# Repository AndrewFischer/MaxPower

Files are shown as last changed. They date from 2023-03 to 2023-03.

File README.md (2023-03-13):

# MaxPower
MaxPower is a dual output buck/boot converter based on the LTC3130. Input power is from an on-board 18650 cell or an external DC source.
Maximum output current is 600mA.<br> 
As shown outputs are 5V and 3.3V. Other voltage pairs are possible. <br>
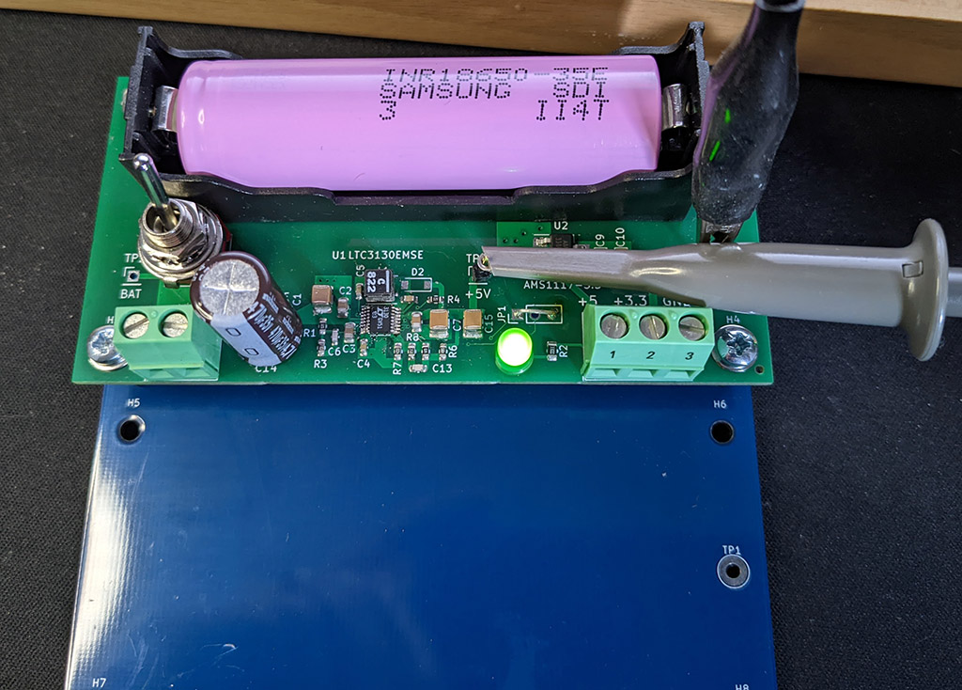
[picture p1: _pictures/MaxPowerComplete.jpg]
Assembled MaxPower


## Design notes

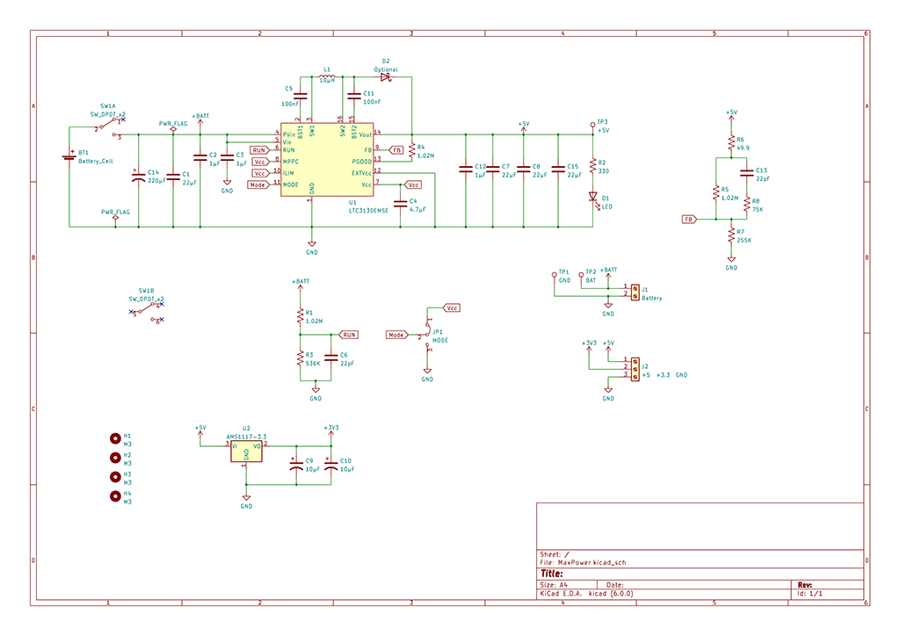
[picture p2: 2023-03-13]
_pictures/MPSchematic.png

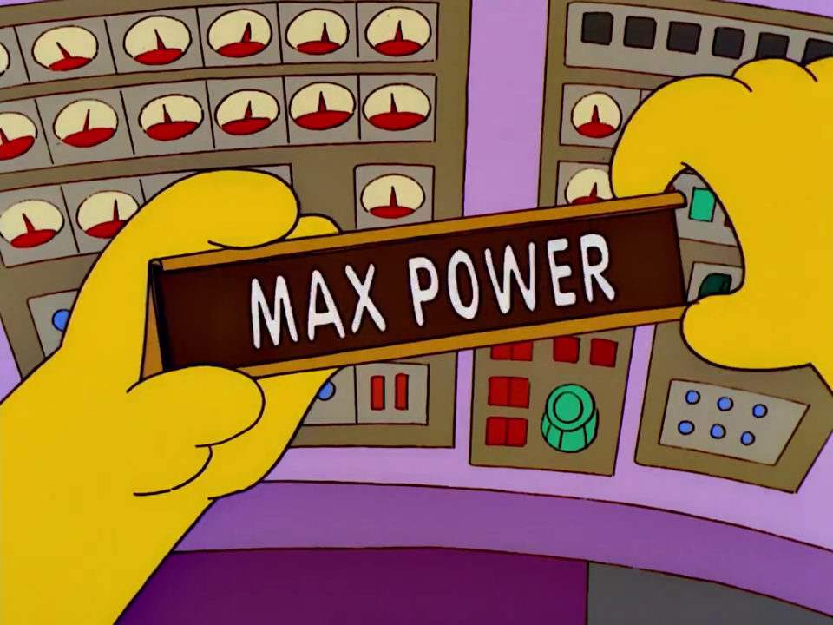
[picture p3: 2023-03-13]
Homer's_new_name.png

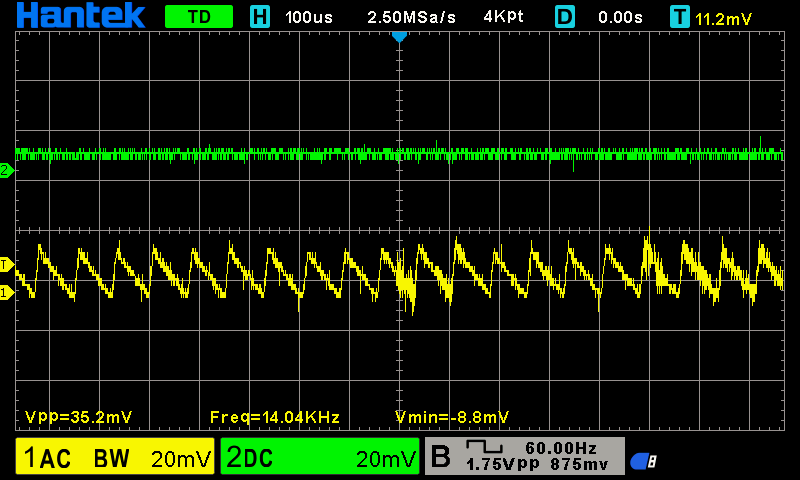
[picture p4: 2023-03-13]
_pictures/NoLoad.png

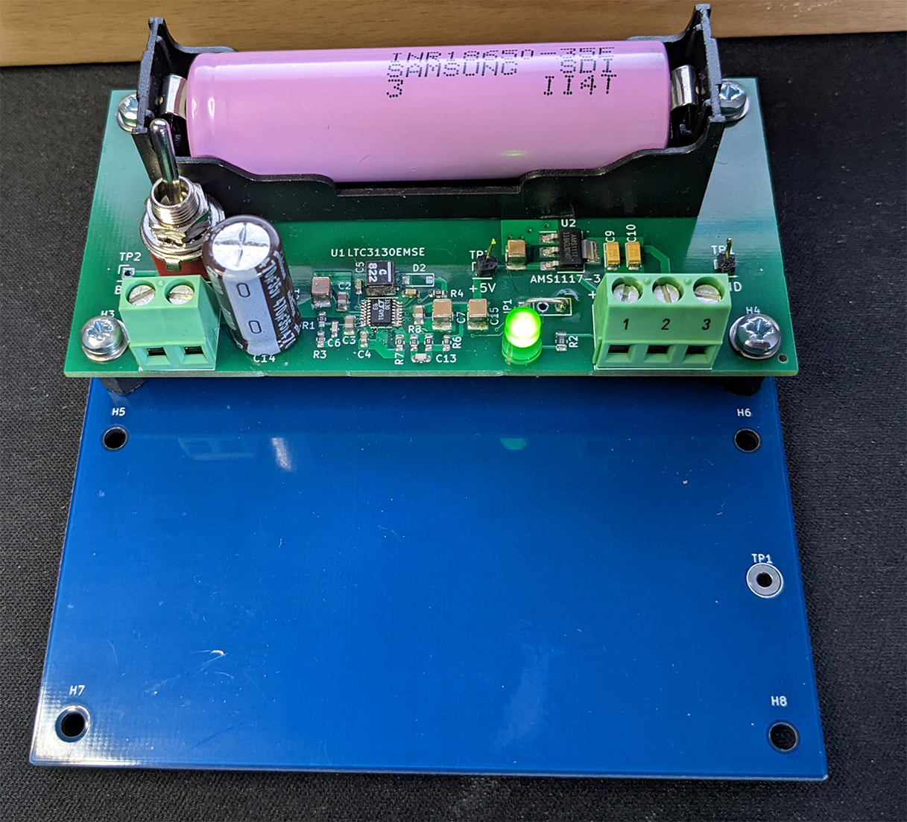
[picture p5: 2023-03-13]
_pictures/Power2.jpg

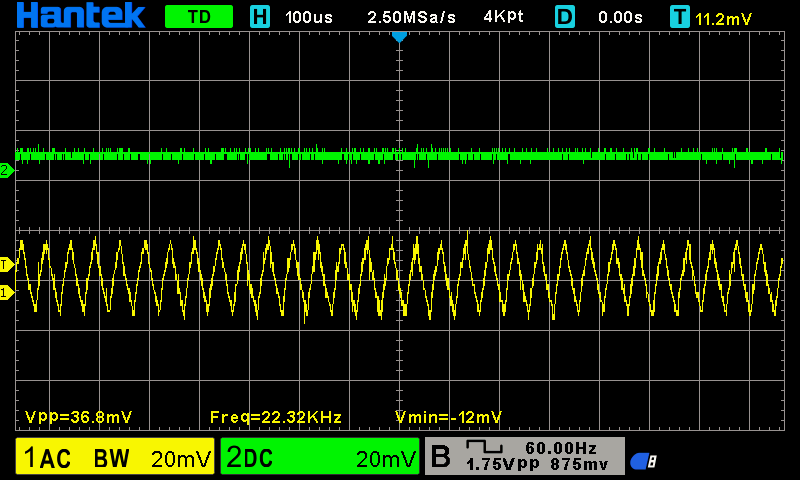
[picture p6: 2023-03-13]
_pictures/LightLoad.png

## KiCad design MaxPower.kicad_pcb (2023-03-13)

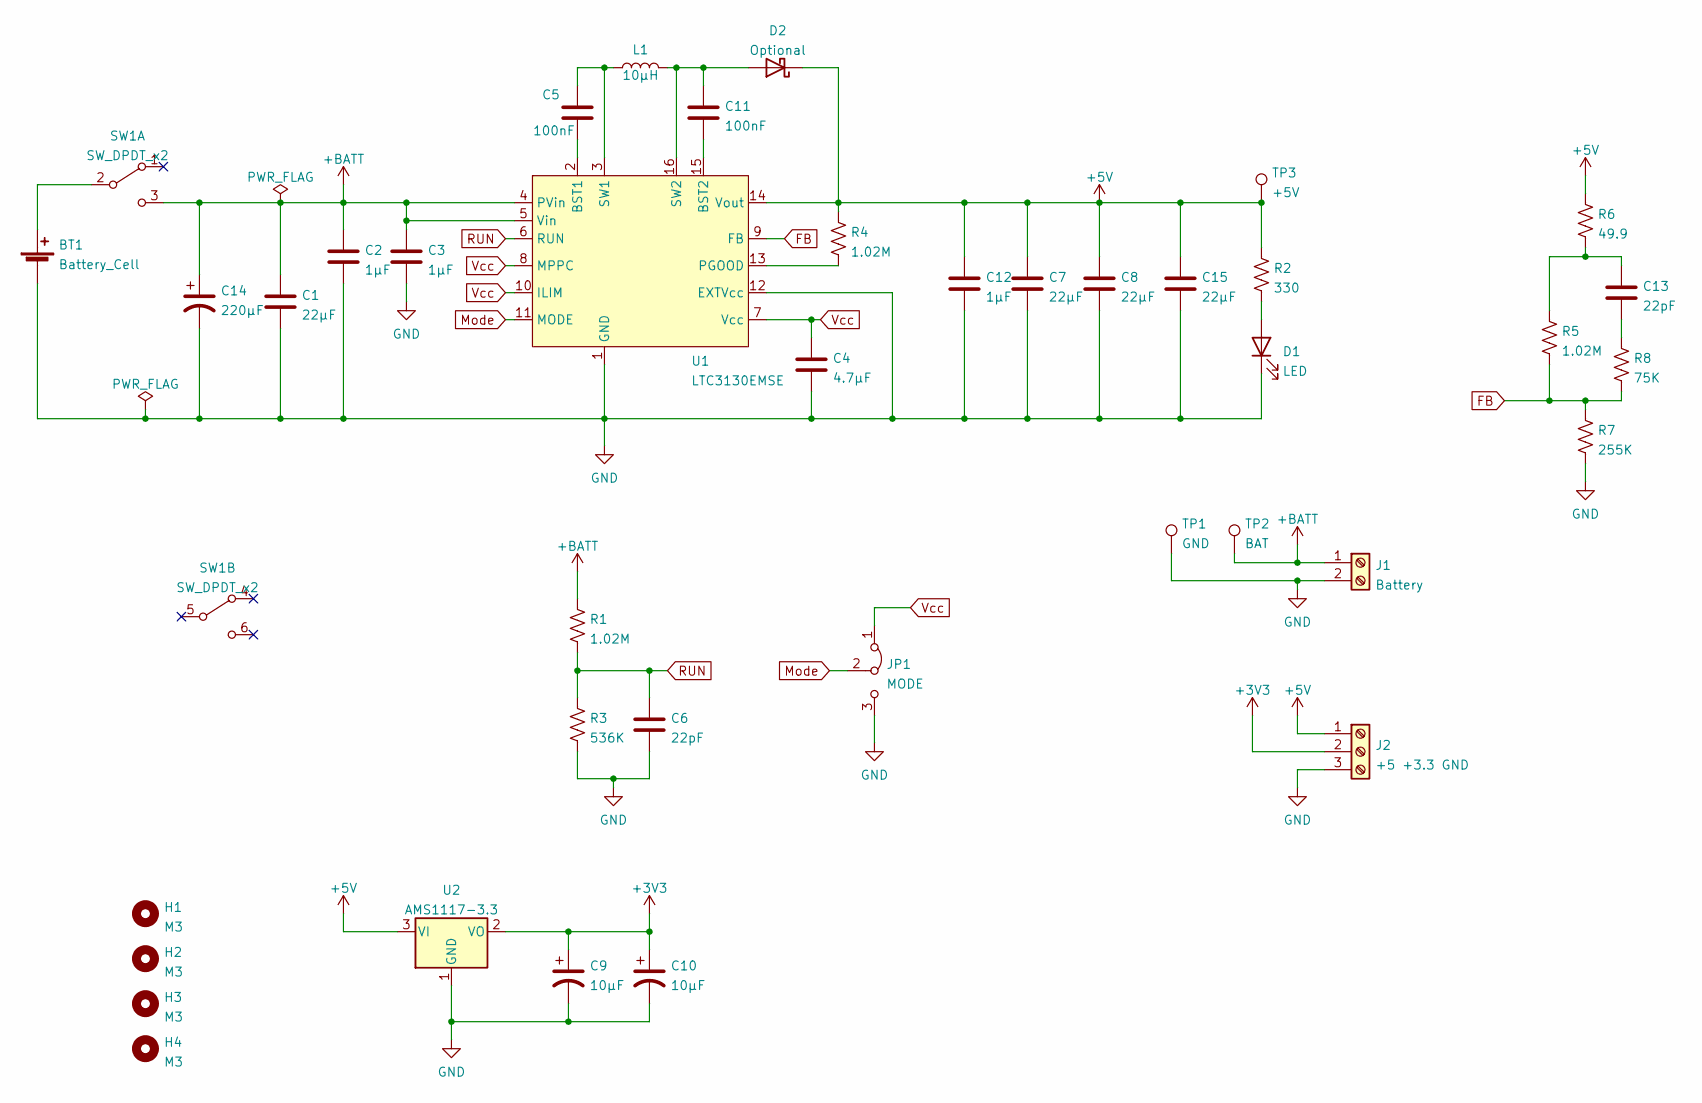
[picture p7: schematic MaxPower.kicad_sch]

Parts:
BT1: Battery_Cell; BatteryHolder_MPD_BH-18650-PC2
C1, C7, C8, C15: 22µF; C_1210_3225Metric; MPN GRM32ER71E226KE15L; LCSC C21397
C2, C3, C12: 1µF; C_0805_2012Metric; MPN CL21B105KBFNNNE; LCSC C28323
C4: 4.7µF; C_0603_1608Metric; MPN GRM188R60J475KE19D; LCSC C71631
C5: 100nF; C_0603_1608Metric; MPN CC0603KRX7R9BB104; LCSC C14663
C6, C13: 22pF; C_0603_1608Metric; MPN CL10C220JB8NNNC; LCSC C1653
C9, C10: 10µF; CP_EIA-3216-18_Kemet-A; LCSC C7171
C11: 100nF; C_0603_1608Metric; LCSC C14663
C14: 220µF; CP_Radial_D8.0mm_P3.50mm; MPN UPA1V271MPD
D1: LED; LED_D3.0mm
D2: Optional; D_SOD-123; MPN B5819W SL; LCSC C8598
H1, H2, H3, H4: M3; MountingHole_3.2mm_M3
J1: Battery; TerminalBlock_Phoenix_MKDS-1,5-2_1x02_P5.00mm_Horizontal
J2: +5 +3.3 GND; TerminalBlock_Phoenix_MKDS-1,5-3_1x03_P5.00mm_Horizontal
JP1: MODE; PinHeader_1x03_P2.54mm_Vertical
L1: 10µH; L_Coilcraft_XxL4030; MPN XGL4030-103
R1, R4, R5: 1.02M; R_0603_1608Metric; MPN RTT031024FTP; LCSC C166909
R2: 330; R_0805_2012Metric; MPN 0805W8F3300T5E; LCSC C17630
R3: 536K; R_0603_1608Metric; MPN 0603WAF5363T5E; LCSC C23200
R6: 49.9; R_0603_1608Metric; MPN 0603WAF499JT5E; LCSC C23185
R7: 255K; R_0603_1608Metric; MPN MCWF06R2553BTL; LCSC C241296
R8: 75K; R_0603_1608Metric; MPN 0603WAF7502T5E; LCSC C23242
SW1: SW_DPDT_x2; 2MD1
TP1: GND; PinHeader_1x01_P2.54mm_Vertical
TP2: BAT; PinHeader_1x01_P2.54mm_Vertical
TP3: +5V; PinHeader_1x01_P2.54mm_Vertical
U1: LTC3130EMSE; MSOP-16-1EP_3x4.039mm_P0.5mm_EP1.651x2.845mm
U2: AMS1117-3.3; SOT-223-3_TabPin2; LCSC C6186

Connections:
+3V3: C9.1, C10.1, J2.2, U2.2 (VO)
+5V: C7.1, C8.1, C12.1, C15.1, D2.1 (K), J2.1, R2.1, R4.1, R6.1, TP3.1, U1.14 (Vout), U2.3 (VI)
+BATT: C1.1, C2.1, C3.1, C14.1, J1.1, R1.1, SW1.3 (C), TP2.1, U1.4 (PVin), U1.5 (Vin)
FB: R5.2, R7.1, R8.2, U1.9 (FB)
GND: BT1.2 (-), C1.2, C2.2, C3.2, C4.2, C6.2, C7.2, C8.2, C9.2, C10.2, C12.2, C14.2, C15.2, D1.1 (K), J1.2, J2.3, JP1.3 (B), R3.2, R7.2, TP1.1, U1.1 (GND), U1.12 (EXTVcc), U1.17 (GND), U2.1 (GND)
Mode: JP1.2 (C), U1.11 (MODE)
unnamed: BT1.1 (+), SW1.2 (B)
unnamed: C5.1, L1.1, U1.3 (SW1)
unnamed: C5.2, U1.2 (BST1)
unnamed: C11.1, D2.2 (A), L1.2, U1.16 (SW2)
unnamed: C11.2, U1.15 (BST2)
unnamed: C13.1, R5.1, R6.2
unnamed: C13.2, R8.1
unnamed: D1.2 (A), R2.2
unnamed: R4.2, U1.13 (PGOOD)
RUN: C6.1, R1.2, R3.1, U1.6 (RUN)
Vcc: C4.1, JP1.1 (A), U1.7 (Vcc), U1.8 (MPPC), U1.10 (ILIM)

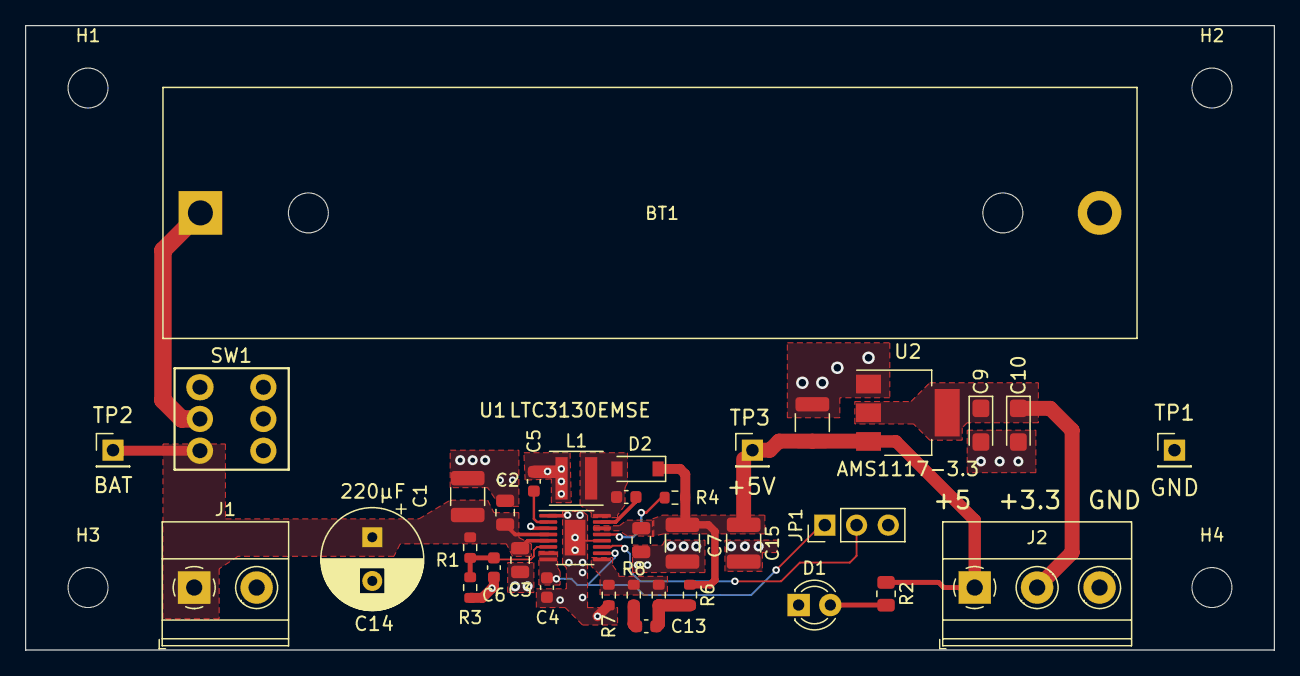
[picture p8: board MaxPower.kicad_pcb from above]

Board: 2 copper layers, 100.0 x 50.0 mm, 40 parts (0 on the bottom side), 17 nets.

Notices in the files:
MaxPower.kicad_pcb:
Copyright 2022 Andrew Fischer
